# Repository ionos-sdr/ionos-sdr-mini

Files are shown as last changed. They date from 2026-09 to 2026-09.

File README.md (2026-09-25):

# Ionos SDR mini

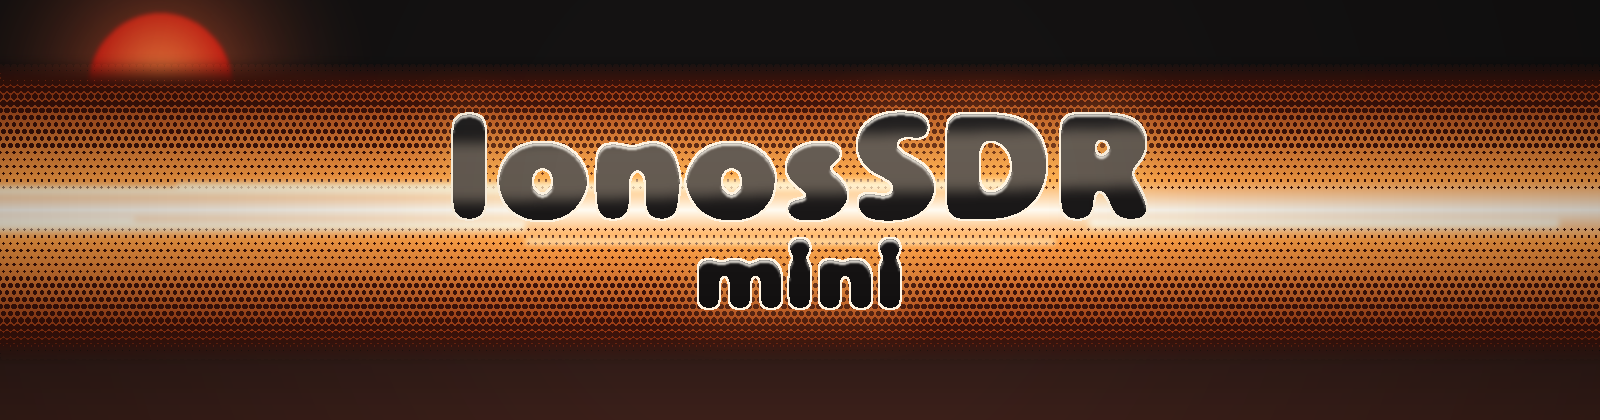
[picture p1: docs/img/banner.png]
Ionos SDR mini


Simplified, low-cost sibling of [Ionos SDR](https://github.com/ionos-sdr/ionos-sdr): a carrier PCB that turns a stock Silicon Labs radio board into a usable SDR. An ESP32-S3 DevKitC sits on female headers on the left, a Silicon Labs radio board plugs into the mezzanine socket on the right, and both displays are optional. No custom RF design, no exotic parts — the radio board you already have in a drawer does the RF.

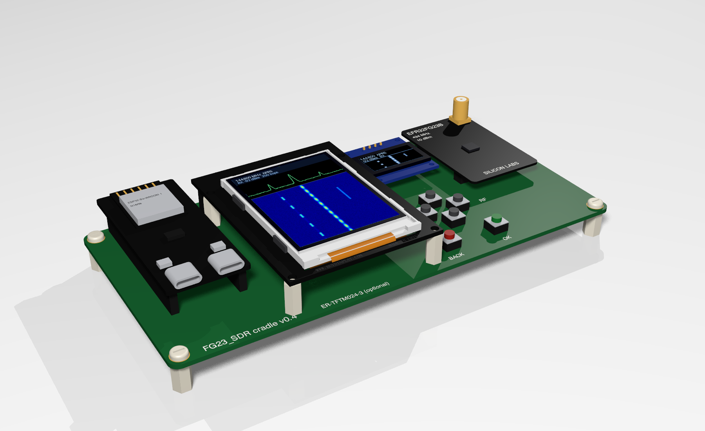
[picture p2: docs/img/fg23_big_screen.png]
Ionos SDR mini v0.4 render: ESP32-S3 DevKitC, 2.4 inch TFT, 0.96 inch OLED, six buttons and an EFR32FG23 radio board on the mezzanine socket


*Design study of the v0.4 layout: DevKitC on headers, optional ER-TFTM024-3 TFT, optional SSD1306 OLED, cursor keys with BACK/OK, and the EFR32FG23 radio board (BRD4265B) on the right.*

**Status: hardware design in progress.** The firmware and the measured facts live in the [main repository](https://github.com/ionos-sdr/ionos-sdr); this repo holds the carrier board and its documentation.

## What it is

- **Carrier only.** 168 x 80 mm, 2-layer, four M3 nylon standoffs. No RF layout risk: matching network, SMA and shielding stay on the Silicon Labs radio board.
- **Any radio board fits.** The mezzanine pair is the standard WSTK radio board interface, so BRD4265B (FG23, 434 MHz, 10 dBm) is only the first panel. The pin-to-signal mapping differs per panel and is selected in firmware.
- **Panel auto-detect.** The radio board's M24C02 board-ID EEPROM sits on the same I2C bus as the OLED, so the firmware can read which panel is plugged in and load the matching pin map at boot.
- **Bootstrap flashing.** SWDIO, SWCLK, SWO and RESET are routed to the ESP32, which bit-bangs SWD. A blank radio board can be programmed with nothing but this board and a USB cable; routine updates then go over the UART command link.
- **One cable.** Power and data over the DevKit's USB-C. The radio gets its own low-noise LDO from the 5 V rail, not the DevKit's shared 3.3 V.

## Architecture

System architecture: Silicon Labs radio board on a mezzanine socket, ESP32-S3 DevKitC carrier with LDO, buttons, optional TFT and OLED, USB or WiFi to the host

- **RX**: FG23 I/Q capture and server-side FFT lines over SPI2 (IO_MUX) to the ESP32-S3, then to the host or to the on-board display.
- **Control**: RDY handshake and a UART command link; SWD is bit-banged by the ESP32 so a blank panel can be programmed with nothing but this board.
- **Power**: a single low-noise LDO feeds VMCU_IN; the radio board's own DC-DC handles PAVDD, so one supply pin powers the whole panel.

## Hardware

| Block | Part | Notes |
| --- | --- | --- |
| MCU | ESP32-S3-DevKitC-1, N16R8 | On 2x22 female headers, antenna end overhanging the board edge |
| Radio | Silicon Labs radio board | 2x 2x20, 1.27 mm mezzanine, 24 mm apart; BRD4265B validated first |
| Display (optional) | EastRising ER-TFTM024-3, 2.4", ILI9341 | 240x320, TE pin wired for tear-free hardware scroll; resistive or capacitive touch |
| Display (optional) | SSD1306 0.96" OLED, I2C | Status line when the large display is not fitted |
| Buttons | 6x tactile, C&K PTS647 | UP/DOWN/LEFT/RIGHT plus BACK/OK, on two resistor ladders |
| Radio supply | LP5907-3.3 or TPS7A2033 | ~6.5 uVrms, fed from the DevKit 5 V rail, ferrite + 10 uF at the connector |

Six buttons cost two pins, not six: each ladder is a 10 k pull-up with the buttons pulling down through 0 R / 2.2 k / 6.8 k / 22 k, read on ADC1 with a 1 k + 100 nF filter at the pin. The freed GPIOs carry the SWD lines.

## Pin mapping (BRD4265B)

The EXP header numbers come from the Silicon Labs radio board documentation; the connector pins are what you actually route. For EXP 3 to 16 the P201 pin number equals the EXP number.

| Signal | ESP32-S3 GPIO | FG23 pin | WSTK net | Connector pin |
| --- | --- | --- | --- | --- |
| SCLK | 12 (SPI2 IO_MUX) | PC05 | WSTK_P12 | P201-15 |
| MOSI | 11 (SPI2 IO_MUX) | PC00 | WSTK_P7 | P201-10 |
| CS | 10 (SPI2 IO_MUX) | PA07 | WSTK_P10 | P201-13 |
| RDY | 14 | PD02 | WSTK_P6 | P201-9 |
| CMD | 13 (UART TX) | PA06 | WSTK_P8 | P201-11 |
| SWDIO | 38 | PA02 | WSTK_P18 | P201-21 |
| SWCLK | 39 | PA01 | WSTK_P20 | P201-23 |
| SWO | 48 | PA03 | WSTK_P16 | P201-19 |
| RESETn | 40 | RESETn | WSTK_F4 | P200-17 |
| BOARD_ID_SDA / SCL | 41 / 42 (I2C0) | - | BOARD_ID | P200-40 / P200-39 |
| VMCU_IN | - | - | VMCU_IN | P201-2 |
| 3V3 | - | - | 3V3 | P200-1 |
| GND | - | - | GND | P200-2, 38; P201-1, 39 |

The FG23 link runs on SPI2 through the IO_MUX pins so the slave interface keeps its headroom for higher clocks; the optional TFT is on SPI3. `VRF` is unused on BRD4265B and the on-board DC-DC feeds PAVDD, so a single supply pin powers the whole panel.

## Repository

```
hardware/          KiCad project, fab outputs, BOM           CERN-OHL-P-2.0
docs/              pin mapping, assembly notes, renders      CC-BY-4.0
```

Firmware lives in the [main repository](https://github.com/ionos-sdr/ionos-sdr): `firmware-fg23/` for the radio SoC, `firmware-esp32/` for the companion.

## Credits, licensing, trademarks

Hardware under CERN-OHL-P-2.0, documentation under CC-BY-4.0. Not affiliated with IONOS SE or Silicon Laboratories; EFR32, Simplicity Studio and the WSTK radio board interface are Silicon Labs property, used here for interoperability only.

Designed by Zoltán Dóczi and Zoltán Papp at [Z2 Labs](https://www.z2labs.io/), Budapest. Design and manufacturing support by [Protowoerk](https://www.protowoerk.com).

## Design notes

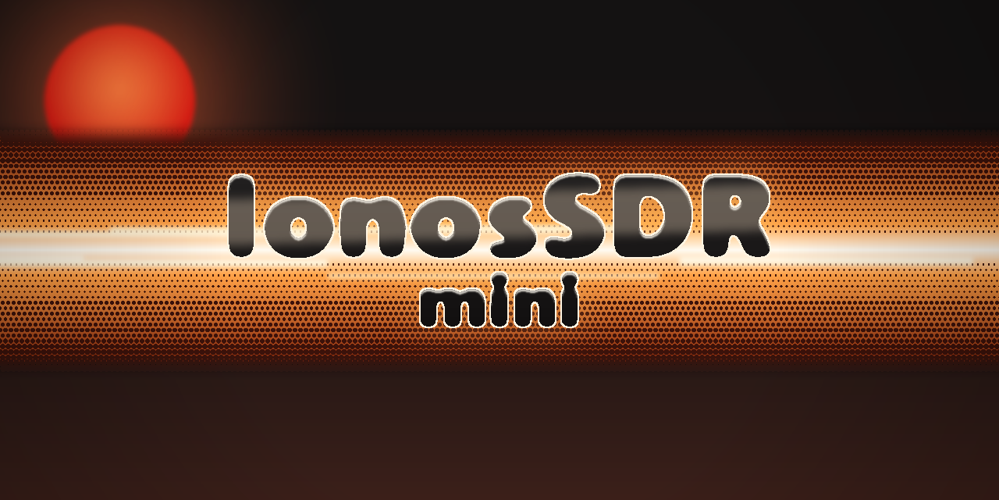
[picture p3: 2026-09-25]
docs/img/social_card.png

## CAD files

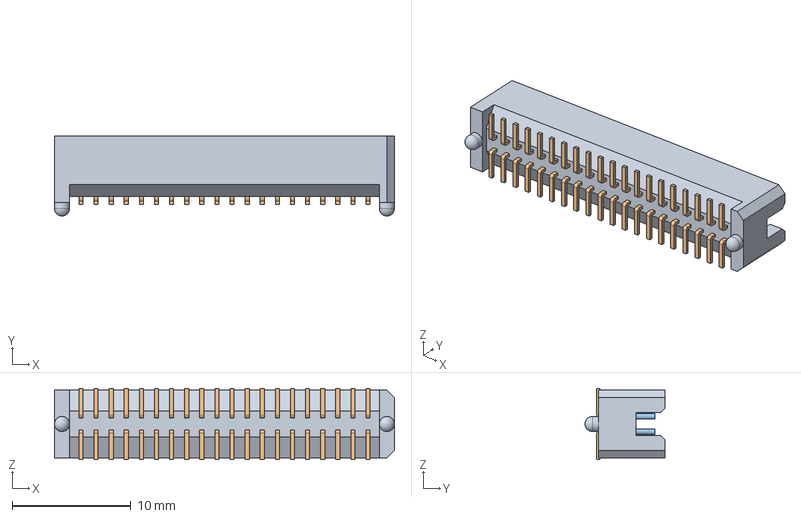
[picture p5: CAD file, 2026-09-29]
CAD/ionosmini_1v0/ionosSDR_mini_3d_models/TFC-120-02-F-D-A.stp
28.6 x 6.73 x 5.97 mm
TFC-120-02-L-D-A_terminal
TFC-120-02-L-D_pins
TFC-120-02-L-D2_pins

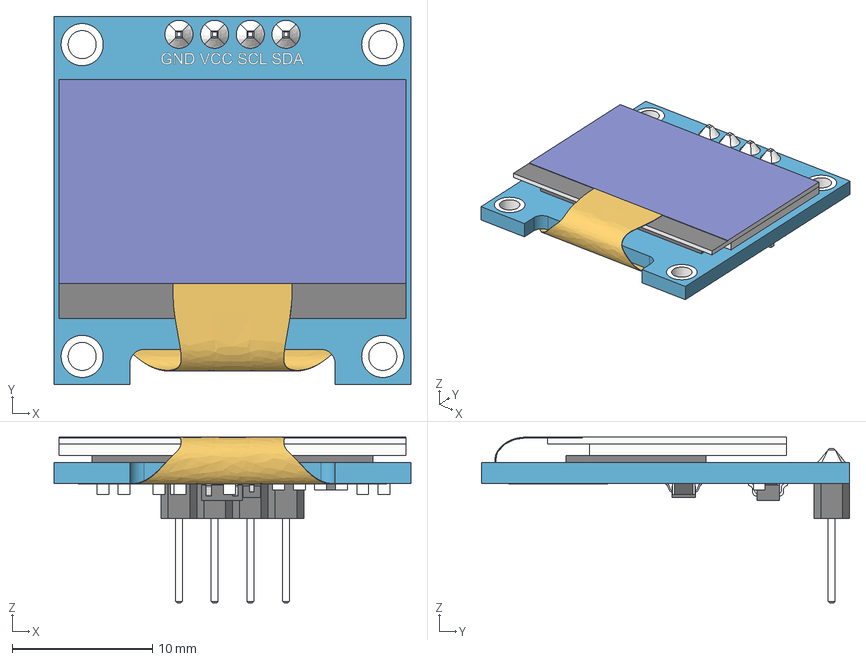
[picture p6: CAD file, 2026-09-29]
CAD/ionosmini_1v0/ionosSDR_mini_3d_models/SSD1306_OLED_Display(128x64).step
25.4 x 26.2 x 11.8 mm
board
screen
pin_header
soldering
smd_capacitor
smd_capacitor (1)
914_smd_resistor
472_smd_resistor x 3
t4_smd_diode
smd_capacitor (2)
smd_capacitor (3)
smd_capacitor (4)
smd_capacitor (5)
smd_capacitor (6)
472_smd_resistor (1)
SOT-23_XC6206 v3
smd_capacitor (7)
flat_cable

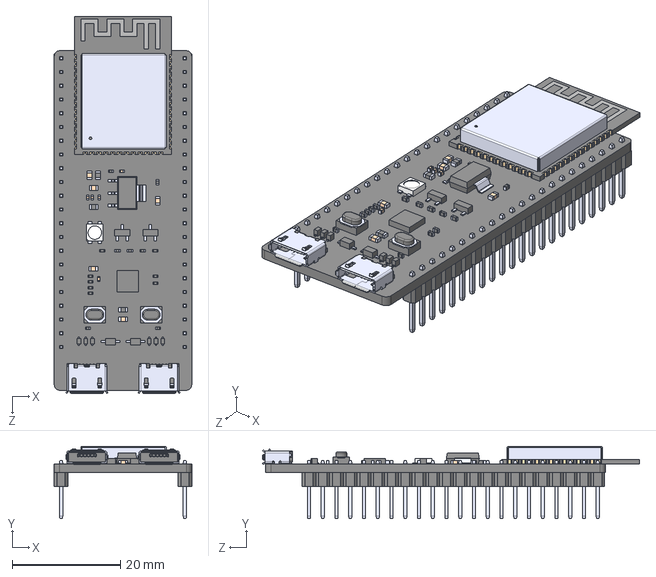
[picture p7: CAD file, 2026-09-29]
CAD/ionosmini_1v0/ionosSDR_mini_3d_models/ESP32-S3-DEVKITC-1-N8R2.step
25.4 x 13.4 x 69.6 mm

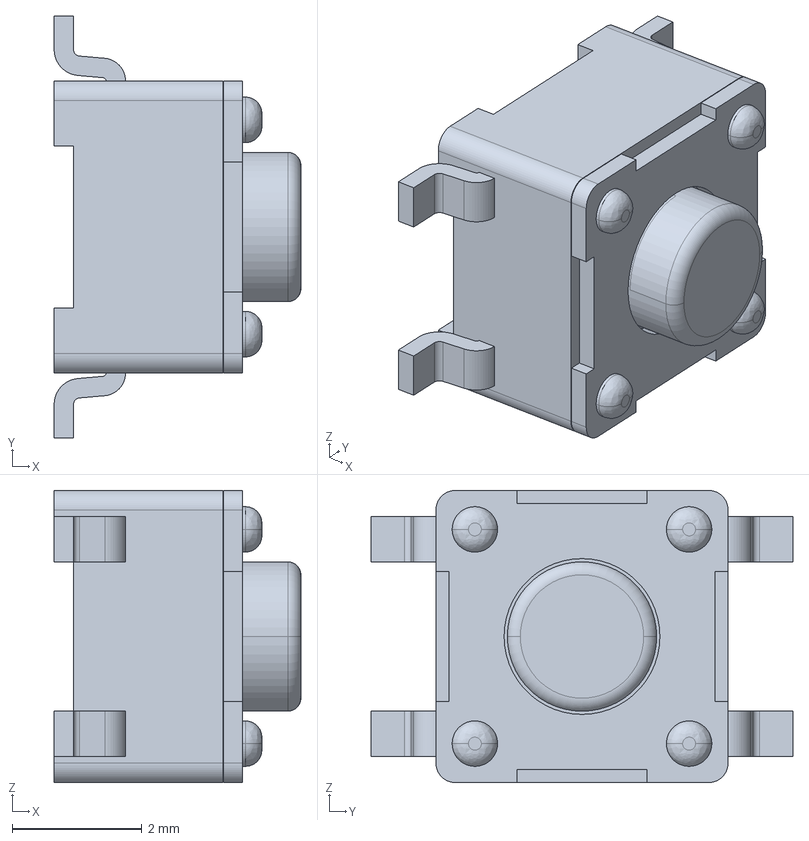
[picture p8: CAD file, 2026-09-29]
CAD/ionosmini_1v0/ionosSDR_mini_3d_models/PTS647SK38SMTR2LFS.stp
3.80 x 6.50 x 4.50 mm

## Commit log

2026-09-25 Add README: carrier board overview, hardware, BRD4265B pin mapping
2026-09-29 CAD mappaban elhelyezve az ionosmini 1v0 fajlok
    [ESP32-S3-DEVKITC-1-N8R2.step, PTS647SK38SMTR2LFS.stp, SSD1306_OLED_Display(128x64).step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]
2026-10-02 Pairing nets to ESP32
    [ionosSDR_mini.kicad_sch]
2026-10-05 chore: gitignore for KiCad backups, caches and generated twin output
2026-10-05 cad(ionosmini_1v0): schematic completed, 4-layer layout routed
    Schematic
    - LP5907MFX-3.3 ultra-low-noise LDO for the radio-board rail (6.5 uVrms
    vs ~66 uVrms for the NCP176), fed from 5V0 through FB1
    - cuttable solder jumpers JP1..JP8 on every signal that leaves at the
    mezzanine, so a wrong connection can be cut and blue-wired; together
    with the existing series R1..R5 and R8 every exit point now has
    exactly one cut point
    - RESETn moved from CON2.17 to CON1.17 (WSTK_F4), TCH_INT/TCH_B swap
    corrected, SW1..SW4 labelled, PWR_FLAGs, no-connects on the unused
    connector pins
    - ER-TFTM024-3 cradle-side socket footprint added (new file)
    Layout
    - 4 layers: F.Cu sign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
    [ionosSDR_mini.kicad_pcb, ionosSDR_mini.kicad_sch]
2026-10-05 twin: PCB digital twin, a pre-fab verifier in four layers
    Not a replacement for ERC or DRC: it proves the wiring is what we think
    it is. The principle is that two independent descriptions must agree -
    a specification written by hand from the manufacturer's own documents,
    against the netlist and the board KiCad produces. The specification is
    never written from our own schematic; that would only prove the
    schematic agrees with itself.
    layer 1 twin_check.py netlist against our own specification
    layer 2 twin_plug.py the radio board plugged in: a walking one is
    stepped across the signals and the twin says
    which EFR32 port pin it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
2026-10-06 fix: 3D model of the mezzanine terminals was 180 deg out
    The STEP attached to TFC-120-02-XX-D-A-K-TR is a different variant
    (TFC-120-02-F-D-A, no -K) and was placed with the plain default
    rotate -90,0,0. Its polarising key therefore sat at the pin-40 end,
    while the WSTK socket keyway is at pin 1.
    Pads and alignment holes were never affected: the pin tips land on
    185.935..210.082 mm and the alignment pins on 184.33/211.71 mm, which
    match the footprint exactly, and the holes are symmetric about the
    centreline so a 180 deg spin cannot move them.
    Set rotate to -90,0,180 in the library footprint and in both board
    instances. DRC: 0 violations, 0 parity problems.
    [ionosSDR_mini.kicad_pcb]
2026-10-07 layout: rev-B, routed to the Olimex house style
    Measured four Olimex OLinuXino boards (A64 rev H, STMP157-LIME2 rev B1,
    LCD-DRIVER rev D, LCD-15.6FHD rev H) and compared our rev-A against them.
    Five differences were real; one was in our favour.
    45 degree grid they run 99.4-100 % of segments on it, we ran 90.8 %.
    The any-angle segments came from the autorouter's
    pull-tight smoothing, which rev-B turns off: 100.00 %.
    width ladder they use 8-24 widths keyed to function, we used two
    (0.25 and 0.45). rev-B has six netclasses -
    0.20 Slow / 0.25 Default+SPI / 0.30 I2C / 0.40 Supply_RB
    / 0.50 P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
    [ionosSDR_mini.kicad_pcb]
2026-10-07 twin: layer 5, the 3D models - the one artefact nothing was checking
    On 2026-10-05 the mezzanine terminals carried TFC-120-02-F-D-A.stp at the
    plain default transform. Two things were wrong and the whole chain missed
    both: the model is not the keyed variant of the part we buy
    (TFC-120-02-XX-D-A-K-TR), and it sat 180 degrees out about Z, putting its
    polarising key at the pin-40 end while the WSTK socket keyway is at pin 1.
    ERC and DRC never look at a 3D model, the alignment pins are symmetric about
    the centreline so a spin does not move them, and the pads were right. It
    took a human staring at the 3D view.
    Layer 5 asks what a machine can answer.
    Text checks, always:
    * is there a model,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
2026-10-08 layout: rev-B2 - new front-panel placement, full re-route
    Placement (agreed from a 1:1 graphical trial before touching the board):
    * small OLED (DISP1) moved up, its top edge on one line with the TFT
    (y = 53.6 mm); its I2C header now sits next to the DevKit's J3_6/J3_7
    * power block (U1, C1-C7, FB1, R8) 31 mm down into the OLED's old place.
    The placement-time estimate said 3V3_RADIO would get ~27 mm longer; the
    routed copper says otherwise - twin layer 3 measures 3V3_RADIO+VMCU_IN
    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
    [ionosSDR_mini.kicad_pcb]
2026-10-08 rev-B2: JLC 4-layer stackup, GND stitching everywhere, twin L3 per layer
    Stackup - JLCPCB JLC04161H-7628 (https://jlcpcb.com/impedance), written into
    the board's setup/stackup block:
    F.Cu 35 um | 7628 PP 0.2104 mm er 4.4 | In1 15.2 um | core 1.065 mm er 4.6
    | In2 15.2 um | 7628 PP 0.2104 mm er 4.4 | B.Cu 35 um ~1.6 mm
    Consequence worth knowing: In2 sits 0.21 mm above B.Cu and 1.08 mm below
    In1, so the near reference - the return path - of everything on In2 is the
    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
    [ionosSDR_mini.kicad_pcb]
2026-10-08 rev-B2: one GND via in every hole of the stitching raster
    Farthest-point fill on top of the 200 mil / 100 mil (radio board) raster:
    wherever a legal spot (barrel inside the GND fill on all four layers, off
    pads, >= 1.2 mm from any via) was farther than 4.0 mm (2.2 mm under the
    radio board) from the nearest GND via, one via went to the centre of that
    hole. 211 vias added, 641 in total.
    DRC 0/0/0 with schematic parity. Twin L1 66/6/0, L2 70/1/0, L3 28/3/0,
    L4 15/3/0, L5 unchanged (non-keyed connector STEP, missing TFT STEP).
    [ionosSDR_mini.kicad_pcb]
2026-10-08 rev-B2: hierarchical GND stitching 200/100/50/25/12.5 mil
    The previous passes only accepted a via where the barrel sat inside the GND
    fill on all four layers, which left the F.Cu GND islands between signal
    traces unstitched. Legality is now judged per layer by real clearance:
    barrel in the In1 GND plane plus at least one more GND fill, >= 0.25 mm
    (0.20 rule + 0.05 margin) from all non-GND copper on every layer, off all
    pads, 0.5 mm from the edge, 1.2 mm from any via.
    Every 200 mil cell (100 mil under the radio board) without a GND via tries
    the cell centre, then the 100, 50, 25, 12.5 mil sub-raster, nearest to the
    centre first. 181 vias added (16 on 200 mil, 78 on 100 mil, 75 on 50 mil,
    9 o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
    [ionosSDR_mini.kicad_pcb]
2026-10-08 rev-B3: full re-route, F.Cu GND copper / In1 signal / In2 GND+power / B.Cu signal
    Layer roles turned around (placement unchanged from rev-B2):
    F.Cu GND copper; tracks only as pad escapes to a via (89 mm in total,
    longest 8.4 mm on 3V3)
    In1.Cu "SIG" signals, asymmetric stripline 0.21 mm under the F.Cu GND
    In2.Cu "GND_PWR" GND plane + all power tracks (5V0, 5V_LDO, 3V3,
    3V3_RADIO, 3V3_RADIO_RB, VMCU_IN)
    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
    [ionosSDR_mini.kicad_pcb]
2026-10-08 rev-B3: GND stitching run to its fixed point (+2 vias)
    The stitching pass stopped at its 8-round cap with 2-4 vias still going in
    per round. Run on to the fixed point: 2 more vias, the next round adds
    nothing. 811 stitching vias, 979 vias in total.
    L4 15/3/0.
    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
    [ionosSDR_mini.kicad_pcb]
2026-10-08 DISP2: buydisplay ER-TFTM024-3 STEP, placed by its mounting holes
    The vendor model (ER-TFTM024-3_3D.zip from buydisplay, SolidWorks 2023,
    2024-06-07) goes into ionosSDR_mini_3d_models/. Alignment measured from
    the STEP geometry: its four 2.8 mm mounting holes (52.0 x 58.5 mm) land
    on the footprint holes with offset X +26.92, Y -32.19; Z +9.31 puts the
    module PCB on an 8.5 mm female socket. The module outline (56.0 x 72.7)
    matches the footprint outline exactly.
    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
    [ER-TFTM024-3.step, ionosSDR_mini.kicad_pcb]
2026-10-08 README: rev-B3 3D render replaces the v0.4 design study
    New render from the rev-B3 board with the manufacturer's TFT model
    (docs/img/ionos-sdr-mini_revB3_3d.png); the old fg23_big_screen.png
    render is removed. The carrier line now says 4-layer
    (JLC04161H-7628, F.Cu GND / In1 signal / In2 GND + power / B.Cu signal)
    instead of 2-layer.
2026-10-08 twin: record the physical ER-TFTM024-3 check (2x20 male header, pin 1 / pin 2 sides match the footprint)
2026-10-09 rev-B3-2L: 2-layer variant, full re-route on both layers
    Same placement as rev-B3, JLC 2-layer FR-4 1.6 mm (F.Cu 35 um | core
    1.53 mm | B.Cu 35 um, er 4.5 assumed - JLC publishes none). No plane: GND
    pour and tracks on both layers, every track is a microstrip over the GND
    pour of the other layer (~128 ohm at 0.25 mm).
    Routing: power -> fast nets -> rest, earlier copper fixed. B.Cu is open
    but costs extra (2 / 3 / 1.5) so it carries crossings and the F.Cu tracks
    keep a GND return path under them; via cost 5000 um. Four variants were
    compared (B.Cu cost and via cost); this one keeps the best return path for
    the fast nets: 74.3 % of their length has GND right under it on the other
    layer, 186 r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
    [ionosSDR_mini.kicad_pcb]
2026-10-09 schematic v2: hierarchical Olimex-style redesign, pin map v2
    Root sheet plus power / radio / ui sheets on A3. Supplies and GND are
    symbols, labels only on pin stubs, 1.27 mm grid, no wire through a body,
    values in Olimex format, not-fitted parts as NA(value). The DevKit symbol
    is split into four units (power, radio link, user interface, reserved).
    Pin map v2 (claude/ionos-mini-pinmap-v2-2026-10-09.md):
    - TCH_B = GPIO21 (header 31), TCH_INT = GPIO9 (header 39)
    - 10k pull-ups to 3V3 on display header 35/36/37 (SD_CS, FONT_CS,
    FLASH_CS), R28-R30; 4.7k pull-ups on TCH_A/TCH_B, R31/R32
    - 10uF + 100nF at the TFT VDD (C11, C12)
    - P201-40 VRF_IN to test point TP8 only; P200-37 5V_RADIO via a
    no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
    [ionosSDR_mini.kicad_sch, power.kicad_sch, radio.kicad_sch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]
2026-10-09 rev-B3-2L PCB: pin map v2 parts, full re-route with 0/45/90 deg tracks
    New parts placed as on the 4-layer board: C11/C12 at the TFT VDD pin,
    R28-R32 header pull-ups under the display socket, R33 (NA 0R) and TP8
    next to the radio board sockets, R34 and the optional SW7 SPARE key.
    All tracks and vias ripped and re-routed in three passes (power, the
    FG23 / TFT buses, the rest), B.Cu open at a cost so it carries short
    crossings and the GND return pour stays mostly whole. Octilinear only:
    0 % any-angle segments, staircases straightened (1259 -> 1067
    segments), then GND stitching on the new geometry (844 vias).
    Design rules: the generic 0.10 mm clearance rule also set the zone
    filler's clearance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
    [TFC-120-02-F-D-A.stp, ionosSDR_mini.kicad_pcb]
2026-10-09 PCB: stitch every GND pour pocket, centre tracks in their channels
    The zone filler drops pieces of GND pour that have no connection
    (island removal), so a strip of GND between two tracks with no via in
    it was simply missing - white holes all over the 2-layer F.Cu. Every
    such pocket now gets a via into connected GND on another layer
    (0.45/0.3 mm where the 0.6/0.3 via does not fit), and the next fill
    keeps it. What is left is narrower than a via, or has no connected
    GND on any other layer to tie to (e.g. between the TFT header rows).
    Straight runs that pass between obstacles on both sides (a track
    between two header pins) are moved to the middle of the channel; the
    neighbouring segments stay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
    [ionosSDR_mini.kicad_pcb]
2026-10-17 SWD debug header CON3 (1x6 2.54 mm, not fitted) for an external debugger
    Flashing the FG23 so far went only through the ESP32's bit-banged SWD.
    CON3 adds a row of six plated holes on the right board edge, outside
    the radio board's outline, for a J-Link / Simplicity Link with a pogo
    clip or solder-in pins. Pin order follows the Tag-Connect TC2030-CTX:
    1 VTref (VMCU_IN), 2 SWDIO, 3 nRESET, 4 SWCLK, 5 GND, 6 SWO.
    The pins are on the radio side of the solder-jumper cut points
    (SWDIO_RB, SWCLK_RB, SWO_RB, RESETn_RB): with JP2 and JP6-JP8 cut the
    ESP32 is off the bus entirely; uncut, firmware keeps its SWD pins as
    inputs while a debugger is attached. VTref only senses VMCU.
    Schematic: radio shee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
2026-10-22 fab: JLCPCB pack - Gerbers, drill, BOM and CPL in one run
    fab/jlc_pack.py writes fab/jlc_<variant>_<date>/: the Gerber + Excellon
    zip (Protel names, no X2, PTH/NPTH apart, mm), the BOM and the CPL in
    JLC's column format, and a report. It refuses to write anything unless
    KiCad DRC (errors, schematic parity) is clean, and it stops on a fitted
    part without an LCSC number or a copper layer missing from the zip.
    JLC assembles the SMD passives, the LDO and the six keys (45 parts,
    13 BOM lines, 11 Basic + 2 Extended). Displays, the DevKit, the Samtec
    sockets, the debug header, solder jumpers, test pads, holes and every
    DNP part are left out.
    fab/jlc_lcsc.csv maps Value + Footprint to an LCSC numb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
2026-10-22 fab: JLC pack - CON1/CON2 as TFM-120-02-L-D-K-TR (C17227108), U1 rotation +180
    TFC-120-02 is out of stock; TFM is the male terminal for the WCON socket on the radio board, same footprint, no alignment pins. LP5907 C80670 needs +180 in the JLC preview. BOM Comment override and p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
2026-10-25 README: KiCad 10 ray-traced 3D renders (2L), manufacturing files section linking the release

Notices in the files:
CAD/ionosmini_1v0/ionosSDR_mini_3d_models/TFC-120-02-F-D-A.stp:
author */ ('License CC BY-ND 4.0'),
